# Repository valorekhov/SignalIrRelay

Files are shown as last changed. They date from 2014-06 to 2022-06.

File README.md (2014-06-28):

SignalIrRelay
=============

ATMEGA328P-based 24 VAC to IR signal relay module. Designed for the use case of connecting 
a single-speed 24VAC thermostat fan output to a high-wall fan coil controlled via an IR remote.  

Features:

* Small board footprint 
* ICSP
* On-board TMP36 ambient temperature sensor and logic that controls fan speed given programmable dT
* Expansion port for the RF Link transmitter.

LICENSE:
Released under CERN Open Hardware License 1.1. See included license.txt file for details.

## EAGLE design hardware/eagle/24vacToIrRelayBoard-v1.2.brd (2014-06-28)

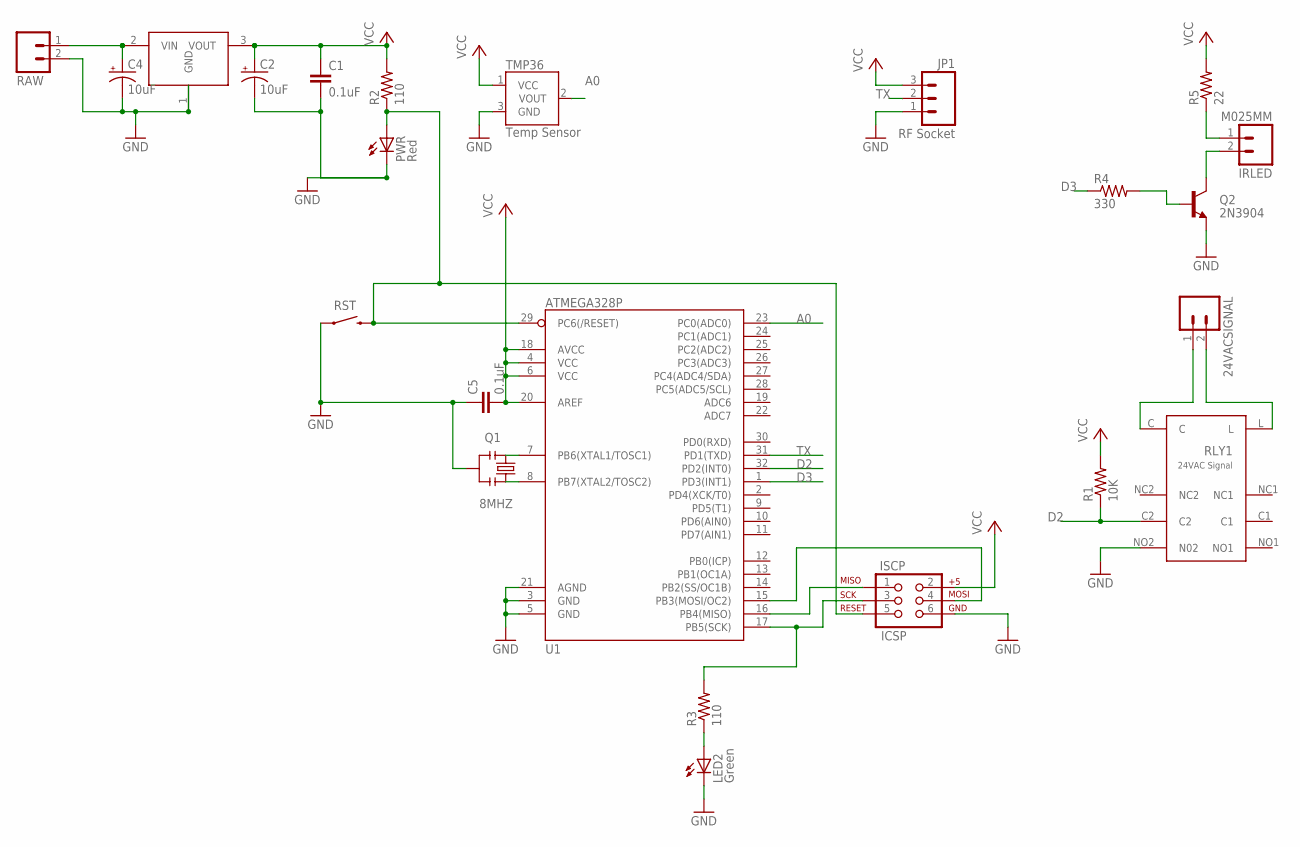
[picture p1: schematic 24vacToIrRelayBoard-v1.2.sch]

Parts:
24VACSIGNAL: M025MM; SCREWTERMINAL-5MM-2
C1, C5: 0.1uF; 0603-CAP
C2, C4: 10uF; EIA3216
IRLED: M025MM; SCREWTERMINAL-5MM-2
ISCP: ICSP; 2X3-NS
JP1: RF Socket; 1X03
LED2: Green; LED-0603
PWR: Red; LED-0603
Q1: 8MHZ; RESONATOR-SMD
Q2: 2N3904; SOT23-3
R1: 10K; 0603-RES
R2, R3: 110; 0603-RES
R4: 330; 0603-RES
R5: 22; 0603-RES
RAW: M025MM; SCREWTERMINAL-5MM-2
RLY1: 24VAC Signal; 976RELAY
RST: SWITCH-MOMENTARY-2PTH; TACTILE-PTH
TMP36: Temp Sensor; TO-92
U1: ATMEGA328P; TQFP32-08
U$1: MCP1702; TO92

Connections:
A0: TMP36.2 (VOUT), U1.23 (PC0(ADC0))
D2: R1.1, RLY1.C2, U1.32 (PD2(INT0))
D3: R4.1, U1.1 (PD3(INT1))
GND: C1.2, C2.C (-), C4.C (-), C5.1, ISCP.6, JP1.1, LED2.C, PWR.C, Q1.2, Q2.2 (E), RAW.2, RLY1.NO2 (N02), RST.1, TMP36.3 (GND), U1.3 (GND), U1.5 (GND), U1.21 (AGND), U$1.1 (GND)
MISO: ISCP.1, U1.16 (PB4(MISO))
MOSI: ISCP.4, U1.15 (PB3(MOSI/OC2))
unnamed: C4.A (+), RAW.1, U$1.2 (VIN)
unnamed: Q1.1, U1.7 (PB6(XTAL1/TOSC1))
unnamed: Q1.3, U1.8 (PB7(XTAL2/TOSC2))
unnamed: LED2.A, R3.1
unnamed: IRLED.1, R5.1
unnamed: IRLED.2, Q2.3 (C)
unnamed: Q2.1 (B), R4.2
unnamed: 24VACSIGNAL.2, RLY1.L
unnamed: 24VACSIGNAL.1, RLY1.C
RST: ISCP.5, PWR.A, R2.1, RST.3 (2), U1.29 (PC6(/RESET))
SCK: ISCP.3, R3.2, U1.17 (PB5(SCK))
TX: JP1.2, U1.31 (PD1(TXD))
VCC: C1.1, C2.A (+), C5.2, ISCP.2, JP1.3, R1.2, R2.2, R5.2, TMP36.1 (VCC), U1.4 (VCC), U1.6 (VCC), U1.18 (AVCC), U1.20 (AREF), U$1.3 (VOUT)

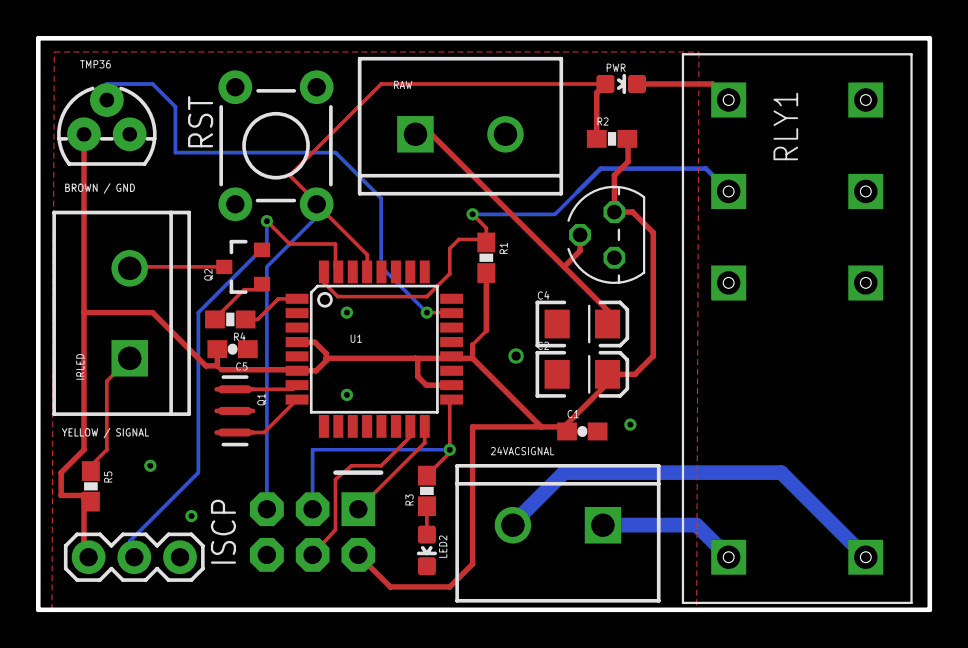
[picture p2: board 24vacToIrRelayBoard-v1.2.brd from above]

Board: 2 copper layers, 49.6 x 31.8 mm, 23 parts (0 on the bottom side), 19 nets.

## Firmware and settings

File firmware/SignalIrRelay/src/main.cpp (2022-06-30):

/*
 * main.cpp
 *
 * Created: 5/24/2014 8:14:21 PM
 *  Author: val
 */ 

//#include <Arduino.h>
#include "Board.h"
#include <stdio.h>
#include <avr/io.h>
#include <util/delay.h>
#include <IRRemote.hpp>

unsigned int codes[4][151] = {
	{
		//Off Sequence
		4950, 2400, 500, 800, 500, 250, 500, 300, 500, 800, 500, 800, 500, 300, 450, 350, 450, 350, 450, 300, 500, 300, 450, 850, 450, 350, 450, 350, 400, 900, 400, 400, 350, 400, 400, 900, 400, 400, 400, 400, 350, 950, 350, 950, 350, 950, 350, 450, 350, 450, 350, 450, 300, 450, 350, 450, 300, 500, 300, 500, 300, 450, 300, 500, 300, 500, 300, 500, 300, 450, 300, 500, 300, 500, 300, 500, 250, 500, 300, 500, 300, 500, 300, 450, 300, 500, 300, 500, 300, 500, 300, 450, 300, 500, 300, 500, 300, 500, 300, 450, 300, 500, 300, 1000, 300, 500, 300, 500, 250, 1050, 300, 450, 300, 500, 300, 500, 300, 450, 300, 500, 300, 500, 300, 1000, 300, 500, 300, 450, 300, 500, 300, 500, 300, 500, 300, 450, 300, 500, 300, 1000, 300, 1000, 300, 500, 300, 500, 300,10000,0,11000,4950
	},
	{
		//Fan LOW sequence, louver High position
		0x1324, 0x9C4, 0x15E, 0x3B6, 0x15E, 0x1C2, 0x15E, 0x1C2, 0x15E, 0x3B6, 0x15E, 0x3B6, 0x15E, 0x1C2,
                0x12C, 0x1C2, 0x15E, 0x1C2, 0x12C, 0x1F4, 0x12C, 0x1F4, 0x12C, 0x3E8, 0x12C, 0x1F4, 0xFA, 0x1F4, 0x12C,
                0x1F4, 0x12C, 0x1F4, 0x12C, 0x3E8, 0x12C, 0x1C2, 0x12C, 0x3E8, 0x12C, 0x3E8, 0x12C, 0x1F4, 0x12C, 0x1F4,
                0x12C, 0x1F4, 0x12C, 0x1C2, 0x12C, 0x1F4, 0x12C, 0x1F4, 0x12C, 0x1F4, 0x12C, 0x1C2, 0x12C, 0x1F4, 0x12C,
                0x1F4, 0x12C, 0x1F4, 0x12C, 0x1C2, 0x12C, 0x1F4, 0x12C, 0x1F4, 0x12C, 0x1F4, 0xFA, 0x1F4, 0x12C, 0x1F4,
                0x12C, 0x1F4, 0x12C, 0x1C2, 0x12C, 0x1F4, 0x12C, 0x1F4, 0x12C, 0x1F4, 0x12C, 0x1C2, 0x12C, 0x1F4, 0x12C,
                0x1F4, 0x12C, 0x1F4, 0x12C, 0x1C2, 0x12C, 0x1F4, 0x12C, 0x1F4, 0x12C, 0x1F4, 0x12C, 0x1C2, 0x12C, 0x3E8,
                0x12C, 0x1F4, 0x12C, 0x1F4, 0x12C, 0x3E8, 0x12C, 0x1C2, 0x15E, 0x1C2, 0x12C, 0x1F4, 0x12C, 0x1F4, 0x12C,
                0x1C2, 0x12C, 0x41A, 0x12C, 0x3E8, 0x12C, 0x1C2, 0x12C, 0x1F4, 0x12C, 0x1F4, 0x12C, 0x1F4, 0xFA, 0x1F4,
                0x12C, 0x1F4, 0x12C, 0x1F4, 0x12C, 0x3E8, 0x12C, 0x3E8, 0x12C, 0x1C2, 0x12C, 0x41A, 0x12C, 10000, 0,
                11000, 4950	},
	{
		//Fan MED sequence, louver High
		0x13BA, 0x8FC, 0x258, 0x2BC, 0x866, 0x2EE, 0x226, 0x2EE, 0x546, 0x96, 0x258, 0xFA, 0x226, 0xFA, 0x226,
                0xC8, 0x226, 0x2EE, 0x226, 0xFA, 0x226, 0xFA, 0x1F4, 0x12C, 0x1F4, 0x320, 0x1F4, 0x12C, 0x1C2, 0x352,
                0x1C2, 0x15E, 0x190, 0x15E, 0x190, 0x190, 0x190, 0x384, 0x190, 0x190, 0x190, 0x190, 0x15E, 0x1C2, 0x15E,
                0x190, 0x190, 0x190, 0x15E, 0x1C2, 0x15E, 0x1C2, 0x15E, 0x1C2, 0x12C, 0x1C2, 0x15E, 0x1C2, 0x12C, 0x1F4,
                0x12C, 0x1F4, 0x12C, 0x1C2, 0x12C, 0x1F4, 0x12C, 0x1F4, 0x12C, 0x1F4, 0xFA, 0x1F4, 0x12C, 0x1F4, 0x12C,
                0x1F4, 0x12C, 0x1C2, 0x12C, 0x1F4, 0x12C, 0x1F4, 0x12C, 0x1F4, 0x12C, 0x1C2, 0x12C, 0x1F4, 0x12C, 0x1F4,
                0x12C, 0x1F4, 0x12C, 0x1C2, 0x12C, 0x1F4, 0x12C, 0x3E8, 0x12C, 0x1F4, 0x12C, 0x1F4, 0x12C, 0x3E8, 0x12C,
                0x1C2, 0x12C, 0x1F4, 0x12C, 0x1F4, 0x12C, 0x1C2, 0x12C, 0x1F4, 0x12C, 0x3E8, 0x12C, 0x3E8, 0x12C, 0x1F4,
                0x12C, 0x1F4, 0x12C, 0x1F4, 0x12C, 0x1C2, 0x12C, 0x1F4, 0x12C, 0x1F4, 0x12C, 0x1F4, 0x12C, 0x3E8, 0x12C,
                0x3E8, 0x12C, 0x1C2, 0x12C, 0x1F4, 0x12C, 10000, 0, 11000, 4950	},
	{
		//Fan High sequence, louver high
		5000, 2350, 500, 800, 500, 250, 550, 250, 550, 750, 550, 750, 550, 250, 500, 300, 500, 300, 500, 250, 500, 300, 450, 850, 450, 350, 450, 350, 400, 900, 400, 400, 350, 400, 400, 950, 350, 400, 400, 400, 350, 950, 400, 900, 400, 900, 350, 450, 350, 450, 350, 450, 300, 450, 350, 450, 350, 450, 300, 500, 300, 450, 300, 500, 300, 500, 300, 500, 300, 450, 300, 500, 300, 500, 300, 500, 250, 500, 300, 500, 300, 500, 300, 450, 300, 500, 300, 500, 300, 500, 300, 450, 300, 500, 300, 500, 300, 500, 250, 500, 300, 500, 300, 1000, 300, 500, 300, 500, 300, 1000, 300, 450, 300, 500, 300, 500, 300, 500, 250, 500, 300, 1000, 300, 1000, 300, 500, 300, 500, 300, 500, 300, 450, 300, 500, 300, 500, 300, 500, 300, 1000, 250, 1050, 300, 450, 300, 1000, 300,10000,0,11000,4950
	}/*,
	{
		 //Fan LOW sequence, louver all positions
                0x1388, 0x92E, 0x226, 0x2EE, 0x226, 0xC8, 0x226, 0xC8, 0x258, 0x2EE, 0x226, 0x2EE, 0x226, 0xFA, 0x1F4,
                0xFA, 0x226, 0xFA, 0x226, 0xFA, 0x1F4, 0x12C, 0x1F4, 0x320, 0x1F4, 0x12C, 0x1C2, 0x15E, 0x1C2, 0x12C,
                0x1C2, 0x15E, 0x190, 0x384, 0x190, 0x384, 0x190, 0x190, 0x190, 0x190, 0x15E, 0x3B6, 0x15E, 0x1C2, 0x15E,
                0x190, 0x190, 0x190, 0x15E, 0x1C2, 0x15E, 0x1C2, 0x15E, 0x1C2, 0x12C, 0x1C2, 0x15E, 0x1C2, 0x15E, 0x1C2,
                0x12C, 0x1F4, 0x12C, 0x1C2, 0x12C, 0x1F4, 0x12C, 0x1F4, 0x12C, 0x1F4, 0x12C, 0x1C2, 0x12C, 0x1F4, 0x12C,
                0x1F4, 0x12C, 0x1C2, 0x12C, 0x1F4, 0x12C, 0x1F4, 0x12C, 0x1F4, 0x12C, 0x1C2, 0x12C, 0x1F4, 0x12C, 0x1F4,
                0x12C, 0x1F4, 0x12C, 0x1C2, 0x12C, 0x1F4, 0x12C, 0x1F4, 0x12C, 0x1F4, 0x12C, 0x1C2, 0x12C, 0x3E8, 0x12C,
                0x1F4, 0x12C, 0x1F4, 0x12C, 0x3E8, 0x12C, 0x1F4, 0x12C, 0x1C2, 0x12C, 0x1F4, 0x12C, 0x1F4, 0x12C, 0x1C2,
                0x12C, 0x41A, 0x12C, 0x3E8, 0x12C, 0x3E8, 0x12C, 0x3E8, 0x12C, 0x1F4, 0x12C, 0x1C2, 0x12C, 0x1F4, 0x12C,
                0x1F4, 0x12C, 0x1F4, 0xFA, 0x1F4, 0x12C, 0x1F4, 0x12C, 0x3E8, 0x12C, 0x1F4, 0x12C, 10000, 0, 11000, 4950	}
                */
};


IRsend irsend;
char currentSpeed;

void fan(uint8_t speed){	
		//LED1(PORT) = speed > 0 ? 1 : 0;
		for(uint8_t i=0; i<2; i++){
			irsend.sendRaw(codes[speed], 151, 38);
		}
		currentSpeed = speed;
}

uint16_t readAdc(uint8_t ch){
	
		ADMUX = (1<<REFS0);
		ADCSRA = (1<<ADEN)|(1<<ADPS2)|(1<<ADPS1)|(1<<ADPS0);

	_delay_ms(2);
	
	// select the corresponding channel 0~7
	ch &= 0b00000111;  // AND operation with 7
	 
	ADMUX = (ADMUX & 0xF8)|ch; // clears the bottom 3 bits before ORing
	
	// start single conversion
	// write �1? to ADSC
	ADCSRA |= (1<<ADSC);
	
	// wait for conversion to complete
	// ADSC becomes �0? again
	// till then, run loop continuously
	while(ADCSRA & (1<<ADSC));
	return (ADC);
}

//Temp is returned as C * 10 to avoid returning a float
int16_t readTemperature(){
	uint16_t reading = readAdc(0);
	float voltagemV = reading * AREFmV / 1023.0 ;  // Voltage at pin in milliVolts = (reading from ADC) * (AREF (mV)/1024)
	return (voltagemV - 500);
}

void blink(uint8_t times){
	for(uint8_t i=0; i<times; i++){
		LED1(PORT) = 1;
		_delay_ms(250);
		LED1(PORT) = 0;
		_delay_ms(250);
	}
}

bool getSwitchReading(){
	char ones=0, zeroes=0, i;
	for(i=0;i<10;i++){		
		if(SW1(IN)){ // read pin == 1
			ones++;
			} else { // read pin == 0
			zeroes++;
		}
		_delay_ms(10);
	}
	return ones>zeroes;
}

int main (void)
{
	int16_t temp = 200;
	char state = 0;
	char speed = 0;
	uint16_t zoneTicks = 0;
	PORTB=0x00;
	PORTD=0x00;	
	LED1(DDR) = 1;
	SW1(DDR) = 0;
		
	//while(1){
			//temp = readTemperature();
			//blink((temp / 10) - 20);
			//_delay_ms(10000);
	//}
	//while(1){
			//bool switchValue = getSwitchReading();
			//if (!switchValue)
				//LED1(PORT) =   1; 
					//else  
				//LED1(PORT) = 0;
			//_delay_ms(100);
	//}

	while(1){
		char switchValue = getSwitchReading();
		//stable reading
		if ( !switchValue ){ // switch is on, action in the zone (no edge transition) 
				if (speed > 0)
					blink(speed);
				if (zoneTicks-- <= 0){
					temp = readTemperature();
					
					//Cooling/heating mode speed selections. Values are in C, x10 to represent fractional C values as int
					if (temp >= 320 || temp <= 190)
						speed = 3;
						else if (temp >= 290 || temp <= 200)
						  speed = 2; 
						  else speed = 1;
				    if (speed != currentSpeed){
						char dif = speed - currentSpeed;
						if (dif > 0){			// Ramp up by stepping through speeds incrementally
							for(uint8_t i = currentSpeed + 1; i< speed; i++){
								fan(i);
								_delay_ms(5000);
							}
						} 
						fan(speed);
						zoneTicks = 300;
					}
				}
			}  else {
				if ( (switchValue ^ state) && switchValue ){ // switch is off, action on edge transition
					LED1(PORT) = 1;
					//Ramp down: run fan on low for approx < 1 min to equalize dT between Tcoil and Tambient
					if (speed != 1)
						fan(1);
					for(uint16_t i = 0; i< 5; i++){
						switchValue = getSwitchReading();
						if (!switchValue)				//call for Fan came in during the ramp down period
							break;
						_delay_ms(900);
					}					
					LED1(PORT) = 0;
					zoneTicks = 0;

					if (switchValue)					//no call for Fan at the end of ramp down, turn fan off.
						fan(0);
				}
				speed = 0;	
			}
			
		if (switchValue ^ state){
			state = switchValue;
		}
		
		//Sleep 
		_delay_ms(900);
	}
}

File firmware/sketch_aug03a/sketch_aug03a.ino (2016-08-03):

#include <IRremote.h>
#include <IRremoteInt.h>


int RECV_PIN = 11;
int BUTTON_PIN = 12;
int STATUS_PIN = 13;

IRrecv irrecv(RECV_PIN);
IRsend irsend;

decode_results results;

void setup()
{
  Serial.begin(9600);
  irrecv.enableIRIn(); // Start the receiver
  pinMode(BUTTON_PIN, INPUT);
  pinMode(STATUS_PIN, OUTPUT);
}

// Storage for the recorded code
int codeType = -1; // The type of code
unsigned long codeValue; // The code value if not raw
unsigned int rawCodes[RAWBUF]; // The durations if raw
int codeLen; // The length of the code
int toggle = 0; // The RC5/6 toggle state

// Stores the code for later playback
// Most of this code is just logging
void storeCode(decode_results *results) {
  codeType = results->decode_type;
  int count = results->rawlen;
  if (codeType == UNKNOWN) {
    Serial.println("Received unknown code, saving as raw");
    codeLen = results->rawlen - 1;
    Serial.println(codeLen);
    // To store raw codes:
    // Drop first value (gap)
    // Convert from ticks to microseconds
    // Tweak marks shorter, and spaces longer to cancel out IR receiver distortion
    for (int i = 1; i <= codeLen; i++) {
      if (i % 2) {
        // Mark
        rawCodes[i - 1] = results->rawbuf[i]*USECPERTICK - MARK_EXCESS;
        //Serial.print(" m");
      } 
      else {
        // Space
        rawCodes[i - 1] = results->rawbuf[i]*USECPERTICK + MARK_EXCESS;
        //Serial.print(" s");
      }
      Serial.print(", 0x");
      Serial.print(rawCodes[i - 1], HEX);
    }
    Serial.println(", 10000,0,11000,4950");
  }
  else {
    if (codeType == NEC) {
      Serial.print("Received NEC: ");
      if (results->value == REPEAT) {
        // Don't record a NEC repeat value as that's useless.
        Serial.println("repeat; ignoring.");
        return;
      }
    } 
    else if (codeType == SONY) {
      Serial.print("Received SONY: ");
    } 
    else if (codeType == PANASONIC) {
      Serial.print("Received PANASONIC: ");
    }
    else if (codeType == JVC) {
      Serial.print("Received JVC: ");
    }
    else if (codeType == RC5) {
      Serial.print("Received RC5: ");
    } 
    else if (codeType == RC6) {
      Serial.print("Received RC6: ");
    } 
    else {
      Serial.print("Unexpected codeType ");
      Serial.print(codeType, DEC);
      Serial.println("");
    }
    Serial.println(results->value, HEX);
    codeValue = results->value;
    codeLen = results->bits;
  }
}

void sendCode(int repeat) {
  if (codeType == NEC) {
    if (repeat) {
      irsend.sendNEC(REPEAT, codeLen);
      Serial.println("Sent NEC repeat");
    } 
    else {
      irsend.sendNEC(codeValue, codeLen);
      Serial.print("Sent NEC ");
      Serial.println(codeValue, HEX);
    }
  } 
  else if (codeType == SONY) {
    irsend.sendSony(codeValue, codeLen);
    Serial.print("Sent Sony ");
    Serial.println(codeValue, HEX);
  } 
  else if (codeType == PANASONIC) {
    irsend.sendPanasonic(codeValue, codeLen);
    Serial.print("Sent Panasonic");
    Serial.println(codeValue, HEX);
  }
  else if (codeType == JVC) {
    irsend.sendPanasonic(codeValue, codeLen);
    Serial.print("Sent JVC");
    Serial.println(codeValue, HEX);
  }
  else if (codeType == RC5 || codeType == RC6) {
    if (!repeat) {
      // Flip the toggle bit for a new button press
      toggle = 1 - toggle;
    }
    // Put the toggle bit into the code to send
    codeValue = codeValue & ~(1 << (codeLen - 1));
    codeValue = codeValue | (toggle << (codeLen - 1));
    if (codeType == RC5) {
      Serial.print("Sent RC5 ");
      Serial.println(codeValue, HEX);
      irsend.sendRC5(codeValue, codeLen);
    } 
    else {
      irsend.sendRC6(codeValue, codeLen);
      Serial.print("Sent RC6 ");
      Serial.println(codeValue, HEX);
    }
  } 
  else if (codeType == UNKNOWN /* i.e. raw */) {
    // Assume 38 KHz
    irsend.sendRaw(rawCodes, codeLen, 38);
    Serial.println("Sent raw");
  }
}

int lastButtonState;

void loop() {
  // If button pressed, send the code.
  int buttonState = digitalRead(BUTTON_PIN);
  if (lastButtonState == HIGH && buttonState == LOW) {
    Serial.println("Released");
    irrecv.enableIRIn(); // Re-enable receiver
  }

  if (buttonState) {
    Serial.println("Pressed, sending");
    digitalWrite(STATUS_PIN, HIGH);
    sendCode(lastButtonState == buttonState);
    digitalWrite(STATUS_PIN, LOW);
    delay(50); // Wait a bit between retransmissions
  } 
  else if (irrecv.decode(&results)) {
    digitalWrite(STATUS_PIN, HIGH);
    storeCode(&results);
    irrecv.resume(); // resume receiver
    digitalWrite(STATUS_PIN, LOW);
  }
  lastButtonState = buttonState;
}

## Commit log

2016-07-30 Increase temp thresholds to favour lower fan speeds for better degumidification
2022-06-30 Platformio fixes; change rampdown
    [main.cpp]

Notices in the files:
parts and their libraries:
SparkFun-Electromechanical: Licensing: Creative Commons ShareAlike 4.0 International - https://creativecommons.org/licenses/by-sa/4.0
